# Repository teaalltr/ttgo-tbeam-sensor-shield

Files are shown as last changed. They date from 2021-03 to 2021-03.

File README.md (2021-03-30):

# Environmental sensor shield for the TTGO TBeam board

This project is OPEN HARDWARE



## Description

This is a shield for the ESP32 board TTGO TBeam v1.1 (with the AXP192), made specifically to connect some evironmental sensors, namely:

- the SPS30 particulate matter sensor ,
- a module for the BME680 
- the LPPYRA03AV pyranometer  
- the SEN0170 anemometer  
- a DCDC boost converter based on the MT3608 

The shield is connected to the SPS30 sensor via a [B5B-ZR(LF)(SN) thru-hole connector](https://www.digikey.it/product-detail/it/jst-sales-america-inc/B5B-ZR-LF-SN/455-1660-ND/926567) (the corresponding crimp terminal is the [ZHR-5](https://www.digikey.it/product-detail/it/jst-sales-america-inc/ZHR-5/455-1201-ND/608642) from JST).

Screw terminals are used, you can find them [here](https://www.amazon.it/gp/product/B07RR7D267/ref=ppx_yo_dt_b_asin_title_o03_s00?ie=UTF8&psc=1)

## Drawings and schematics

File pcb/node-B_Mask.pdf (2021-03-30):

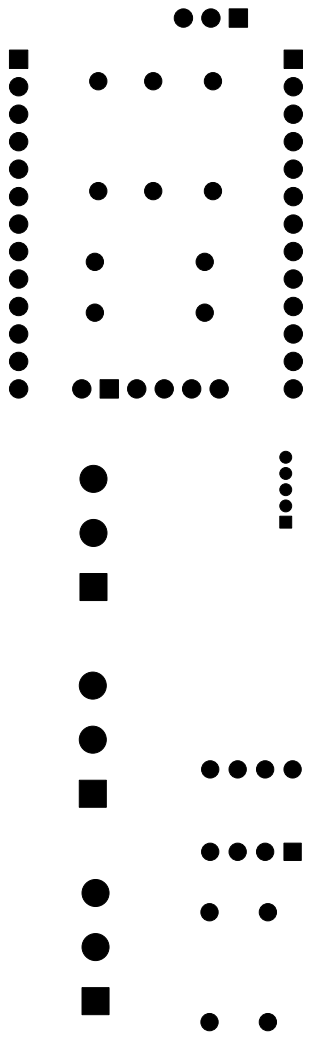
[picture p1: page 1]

File: node.kicad_pcb Sheet:
Id: 1/1 Title: Layout PCB scheda shield per TTGO T-Beam v1.1

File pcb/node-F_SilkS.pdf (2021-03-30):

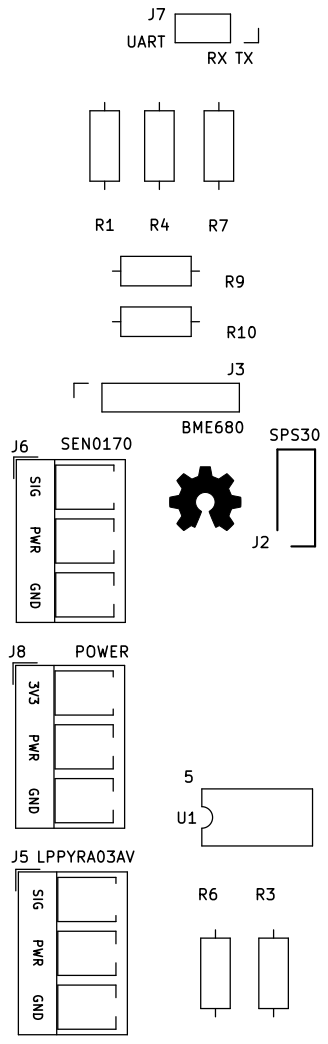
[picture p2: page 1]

File: node.kicad_pcb Sheet: PWR 3V3 SIG PWR SIG PWR GND GND GND

Id: 1/1 Title: Layout PCB scheda shield per TTGO T-Beam v1.1

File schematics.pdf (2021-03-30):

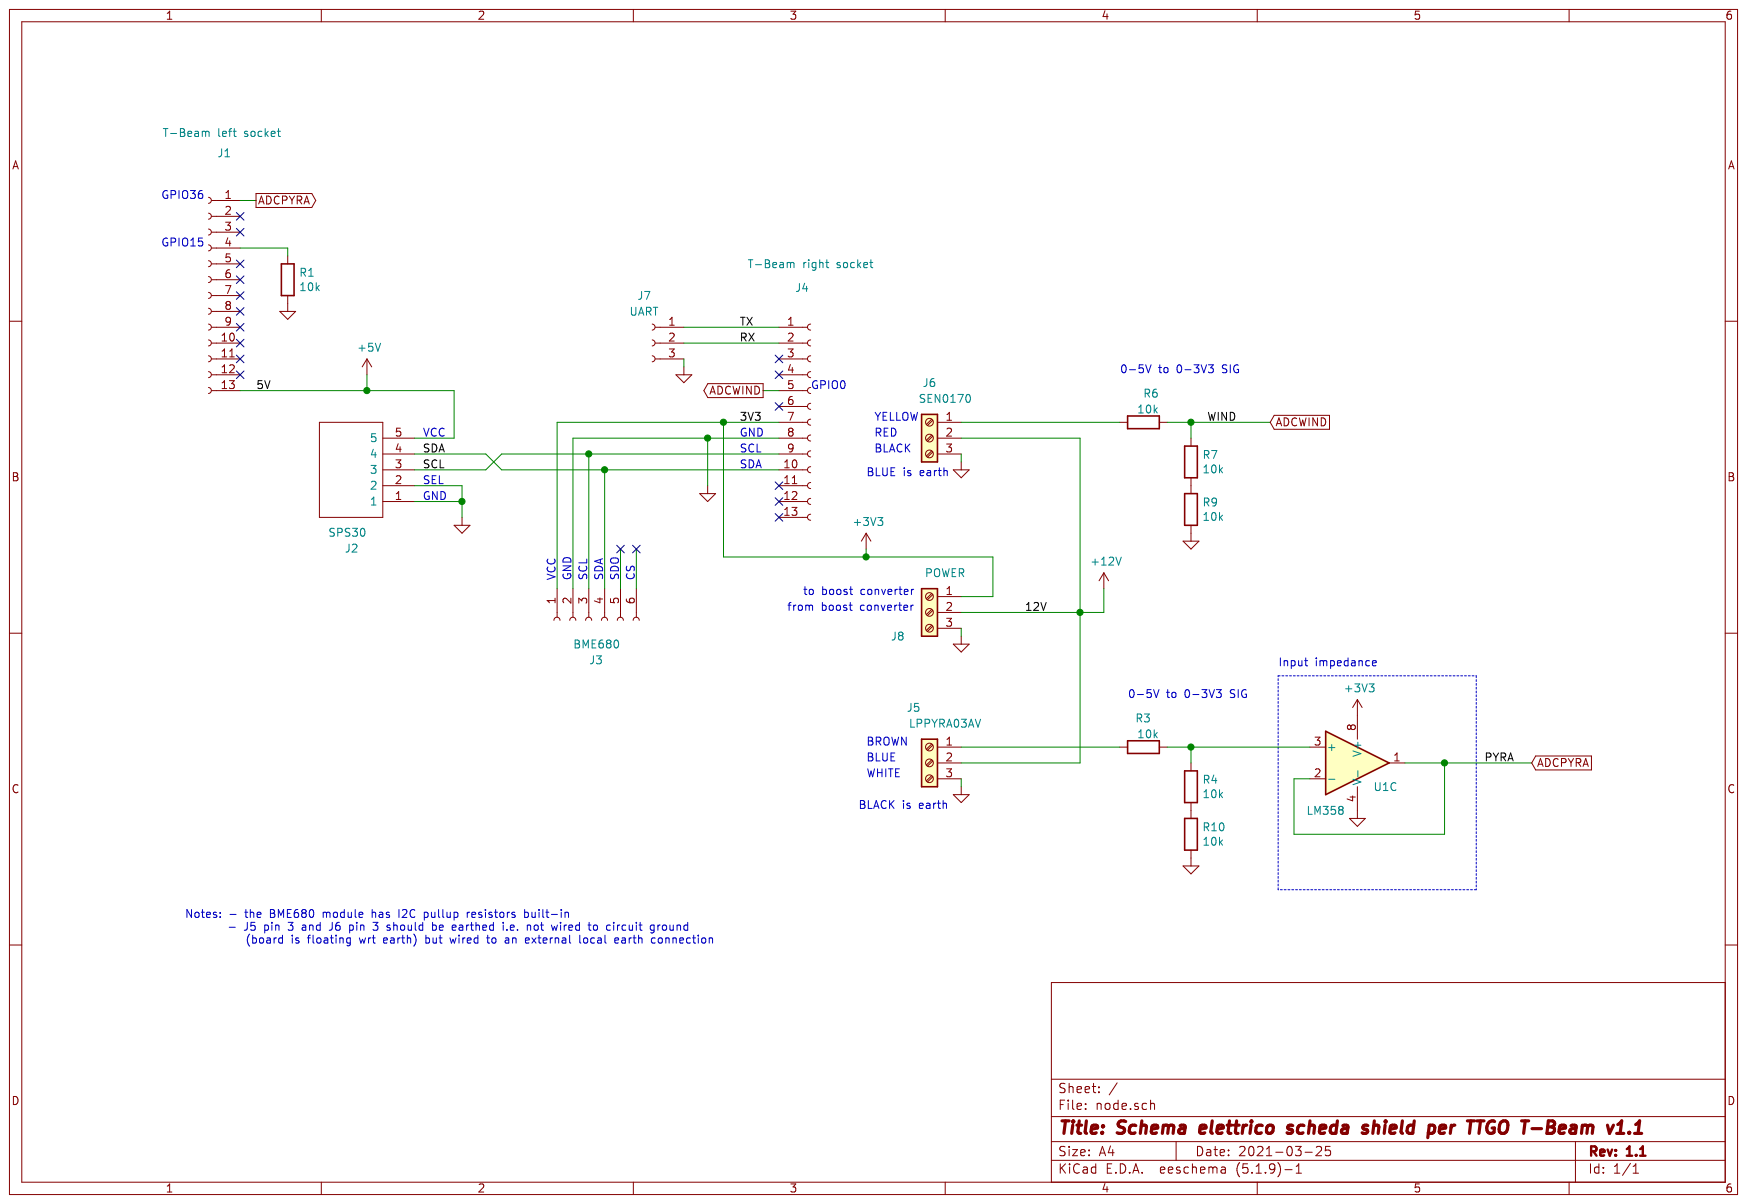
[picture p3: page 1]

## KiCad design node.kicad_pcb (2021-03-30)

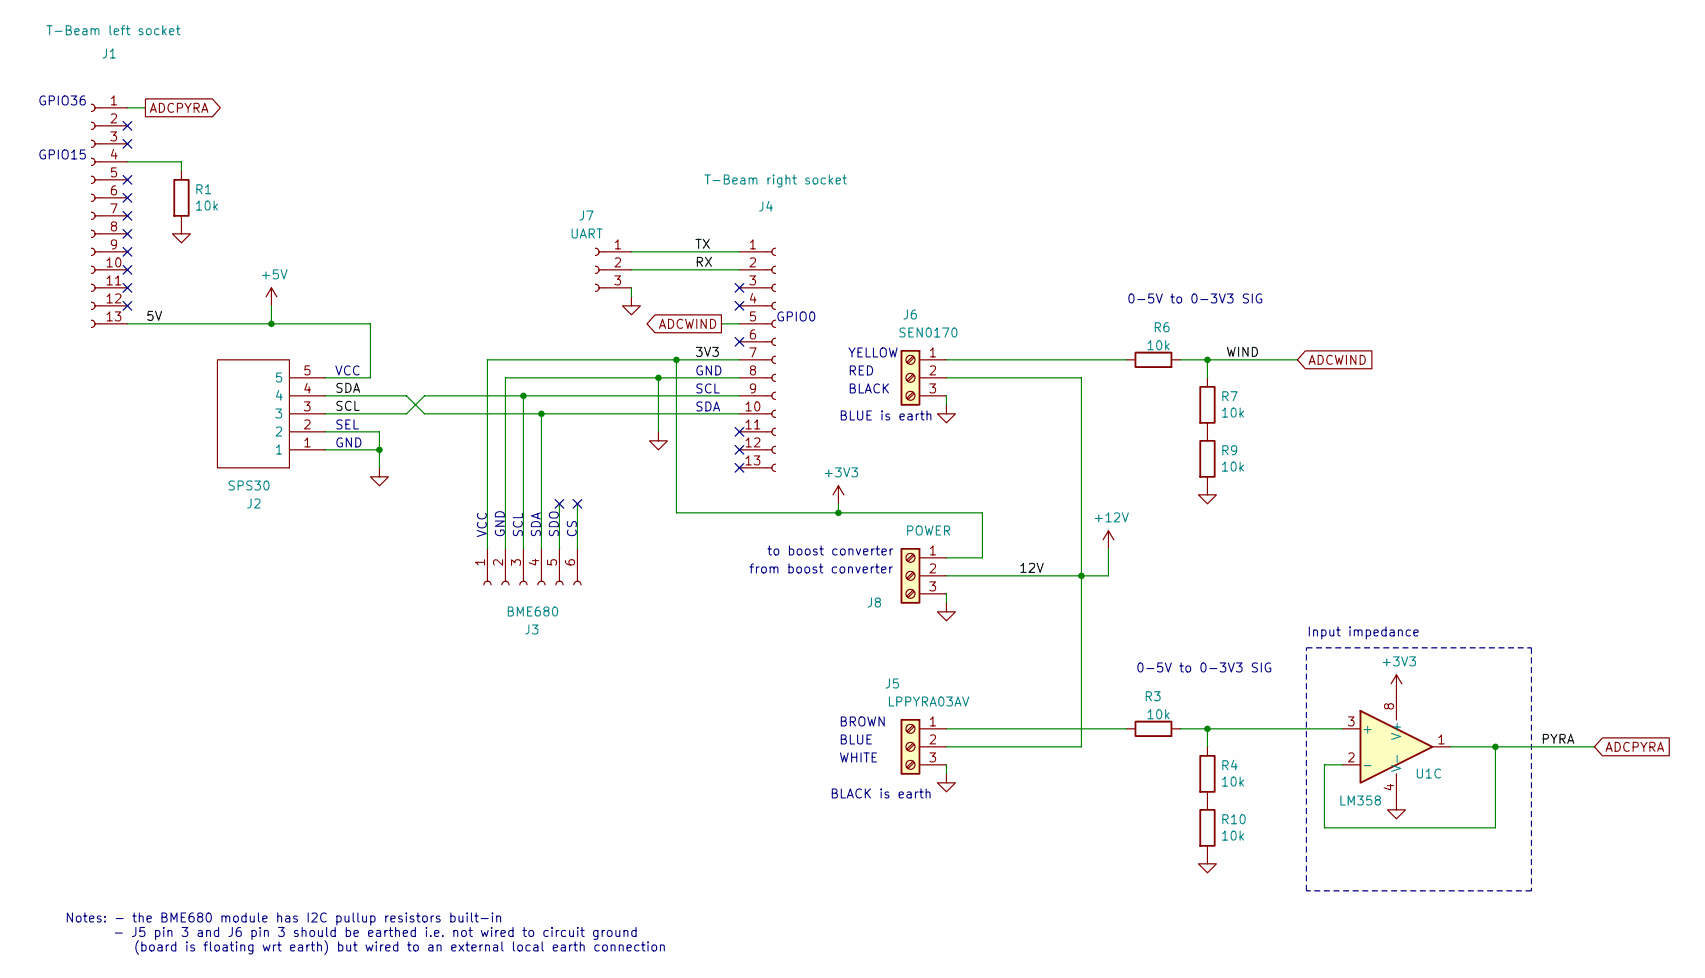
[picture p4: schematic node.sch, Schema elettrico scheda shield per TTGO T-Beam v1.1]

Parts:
J1: T-Beam left socket; PinSocket_1x13_P2.54mm_Vertical
J2: SPS30; SHDR5W50P0X150_1X5_900X350X450P; Manufacturer_Part_Number B5B-ZR (LF)(SN); Mouser Part Number N/A
J3: BME680; PinSocket_1x06_P2.54mm_Vertical
J4: T-Beam right socket; PinSocket_1x13_P2.54mm_Vertical
J5: LPPYRA03AV; TerminalBlock_RND_205-00277_1x03_P5.00mm_Vertical
J6: SEN0170; TerminalBlock_RND_205-00277_1x03_P5.00mm_Vertical
J7: UART; PinSocket_1x03_P2.54mm_Vertical
J8: POWER; TerminalBlock_RND_205-00277_1x03_P5.00mm_Vertical
R1, R3, R4, R6, R7, R9, R10: 10k; R_Axial_DIN0207_L6.3mm_D2.5mm_P10.16mm_Horizontal
U1: LM358; DIP-8_W7.62mm

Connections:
+3V3: J3.1, J4.7, J8.1, U1.8 (V+)
+5V: J1.13, J2.5
+12V: J5.2, J6.2, J8.2
/RX: J4.2, J7.2
/SCL: J2.3, J3.3, J4.9
/SDA: J2.4, J3.4, J4.10
/TX: J4.1, J7.1
ADCPYRA: J1.1, U1.1, U1.2 (-)
ADCWIND: J4.5, R6.2, R7.1
GND: J2.1, J2.2, J3.2, J4.8, J5.3, J6.3, J7.3, J8.3, R1.2, R9.2, R10.2, U1.4 (V-)
unnamed: J1.4, R1.1
unnamed: J5.1, R3.1
unnamed: J6.1, R6.1
unnamed: R3.2, R4.1, U1.3 (+)
unnamed: R7.2, R9.1
unnamed: R4.2, R10.1

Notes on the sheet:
Notes: - the BME680 module has I2C pullup resistors built-in - J5 pin 3 and J6 pin 3 should be earthed i.e. not wired to circuit ground (board is floating wrt earth) but wired to an external local earth connection
0-5V to 0-3V3 SIG
Input impedance
to boost converter
from boost converter
BLACK is earth
BROWN
SDA
SDO
SCL
GND
WHITE
GPIO0
BLUE is earth
RED
BLACK
YELLOW
BLUE
GPIO15
VCC
GPIO36
SEL

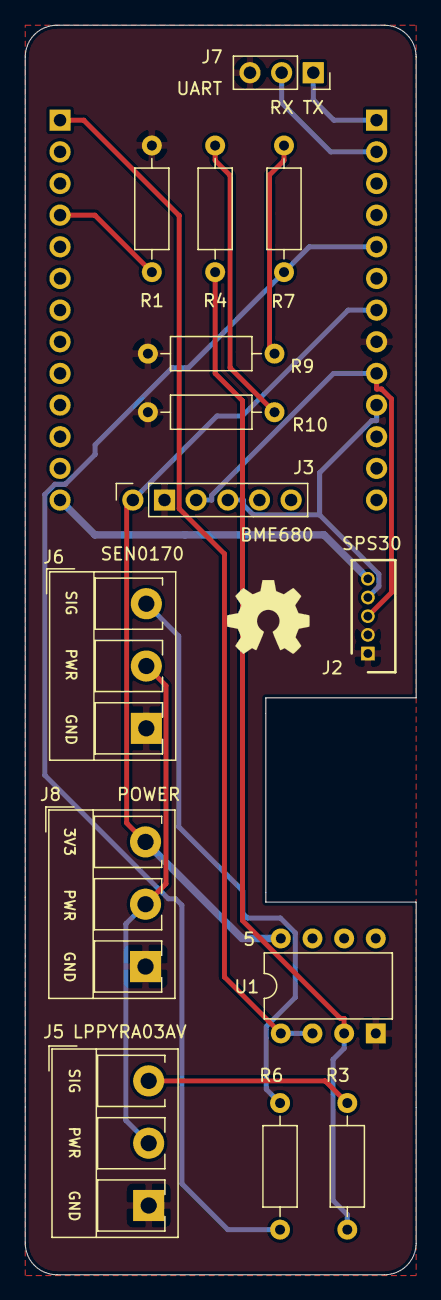
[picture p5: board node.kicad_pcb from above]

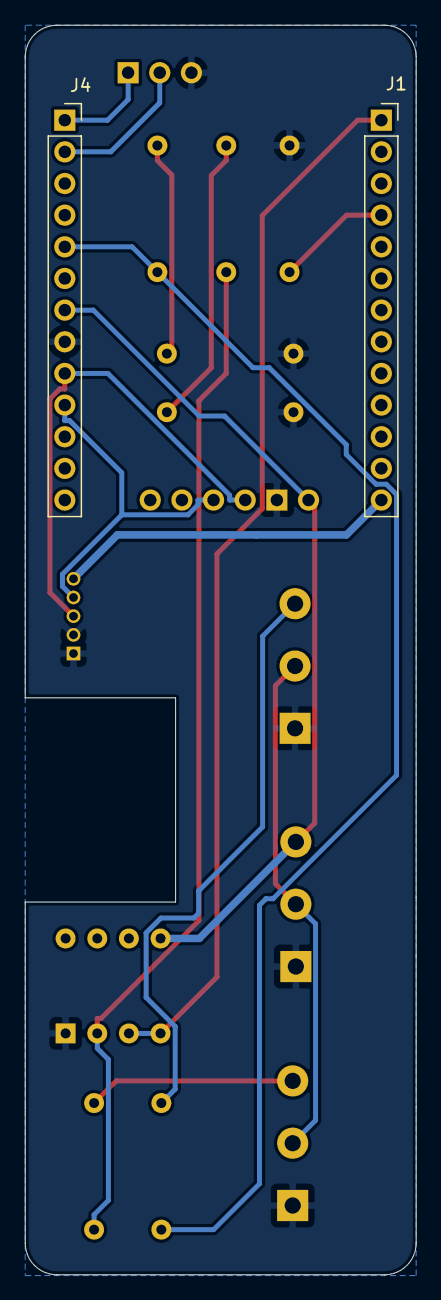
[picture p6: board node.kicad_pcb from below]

Board: 2 copper layers, 31.4 x 100.3 mm, 16 parts (2 on the bottom side), 16 nets.

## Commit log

2021-03-30 Initial drop
    [node.kicad_pcb, node.sch]
2021-03-30 add schematics pdf
2021-03-30 add PCB layers PDF

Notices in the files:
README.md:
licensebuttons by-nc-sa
